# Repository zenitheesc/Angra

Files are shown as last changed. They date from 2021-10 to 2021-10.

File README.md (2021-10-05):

<h1 align="center" style="color:white; background-color:black">Angra</h1>
<h4 align="center">Power bank to power different systems in stratospheric probes</h4>

<p align="center">
	<a href="http://zenith.eesc.usp.br/">
    
    </a>
    <a href="https://eesc.usp.br/">
    
    </a>
    <a href="https://github.com/${{ env.REPOSITORY_FULL_NAME }}/blob/main/LICENSE">
    
    </a>
    <a href="https://github.com/${{ env.REPOSITORY_FULL_NAME }}/issues">
    
    </a>
    <a href="https://github.com/${{ env.REPOSITORY_FULL_NAME }}/commits/main">
    
    </a>
    <a href="https://github.com/${{ env.REPOSITORY_FULL_NAME }}/graphs/contributors">
    
    </a>
    <a href="https://github.com/${{ env.REPOSITORY_FULL_NAME }}/commits/main">
    
    </a>
    <a href="https://github.com/${{ env.REPOSITORY_FULL_NAME }}/issues">
    
    </a>
    <a href="https://github.com/${{ env.REPOSITORY_FULL_NAME }}/pulls">
    
    </a>
</p>

<p align="center">
    <a href="#environment-and-tools">Environment and Tools</a> •
    <a href="#board">Board</a>
</p>

## Environment and tools

This system was designed using Eagle v.9.4.2

## Board

<p align = "center">
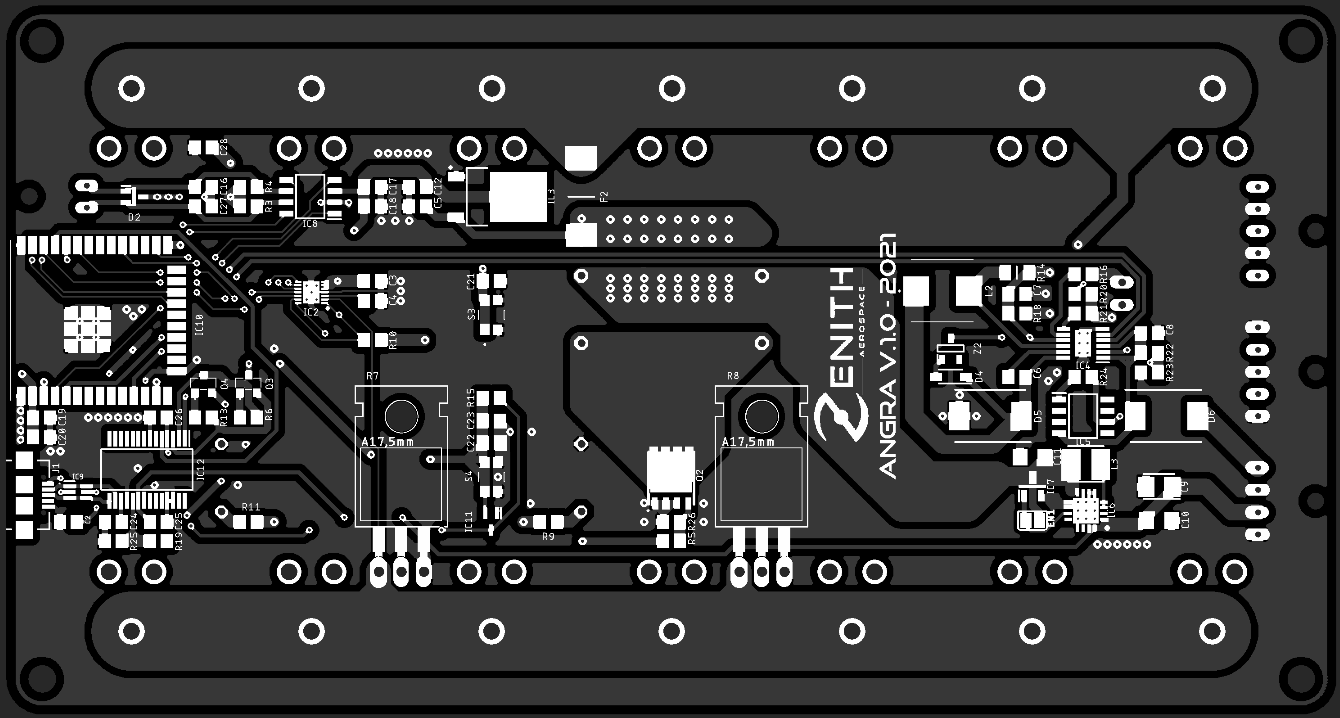
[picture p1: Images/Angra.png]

</p>

It supplies power to up to 5 systems with the voltage of its own batteries and 1 with 5V, in addition to ensuring the health of the batteries, solar charging and wireless monitoring of the status.

---

<p align="center">
    <a href="http://zenith.eesc.usp.br">
    
    </a> 
    <a href="https://www.facebook.com/zenitheesc">
    
    </a> 
    <a href="https://www.instagram.com/zenith_eesc/">
    
    </a>

</p>
<p align = "center">
<a href="zenith.eesc@gmail.com">zenith.eesc@gmail.com</a>
</p>

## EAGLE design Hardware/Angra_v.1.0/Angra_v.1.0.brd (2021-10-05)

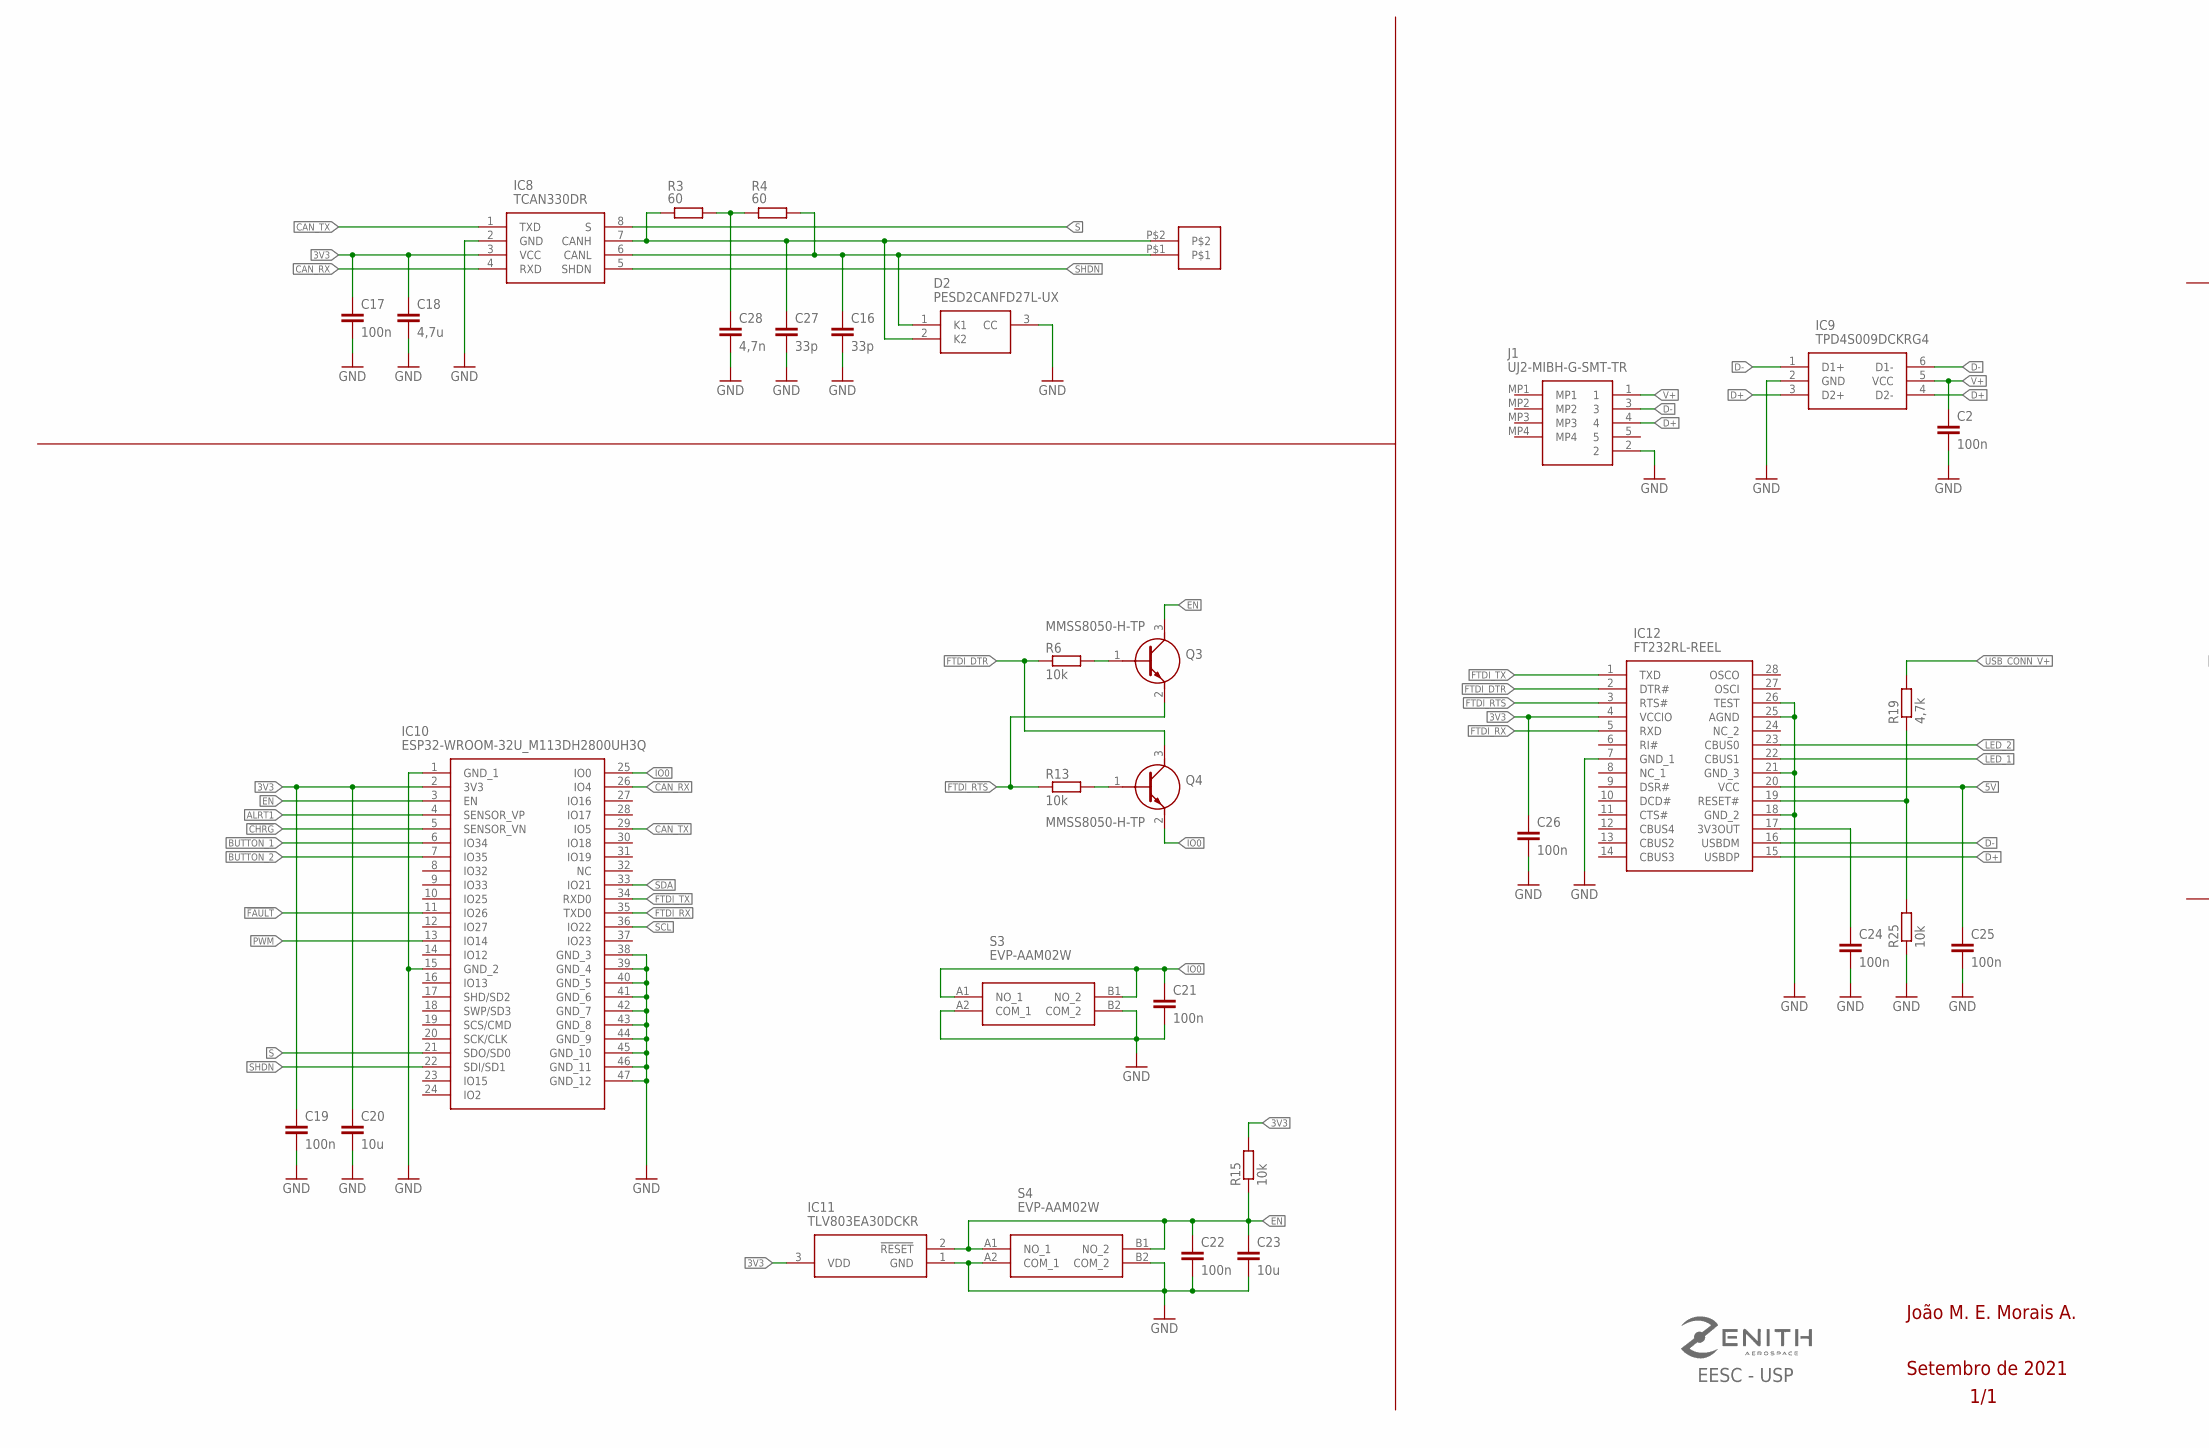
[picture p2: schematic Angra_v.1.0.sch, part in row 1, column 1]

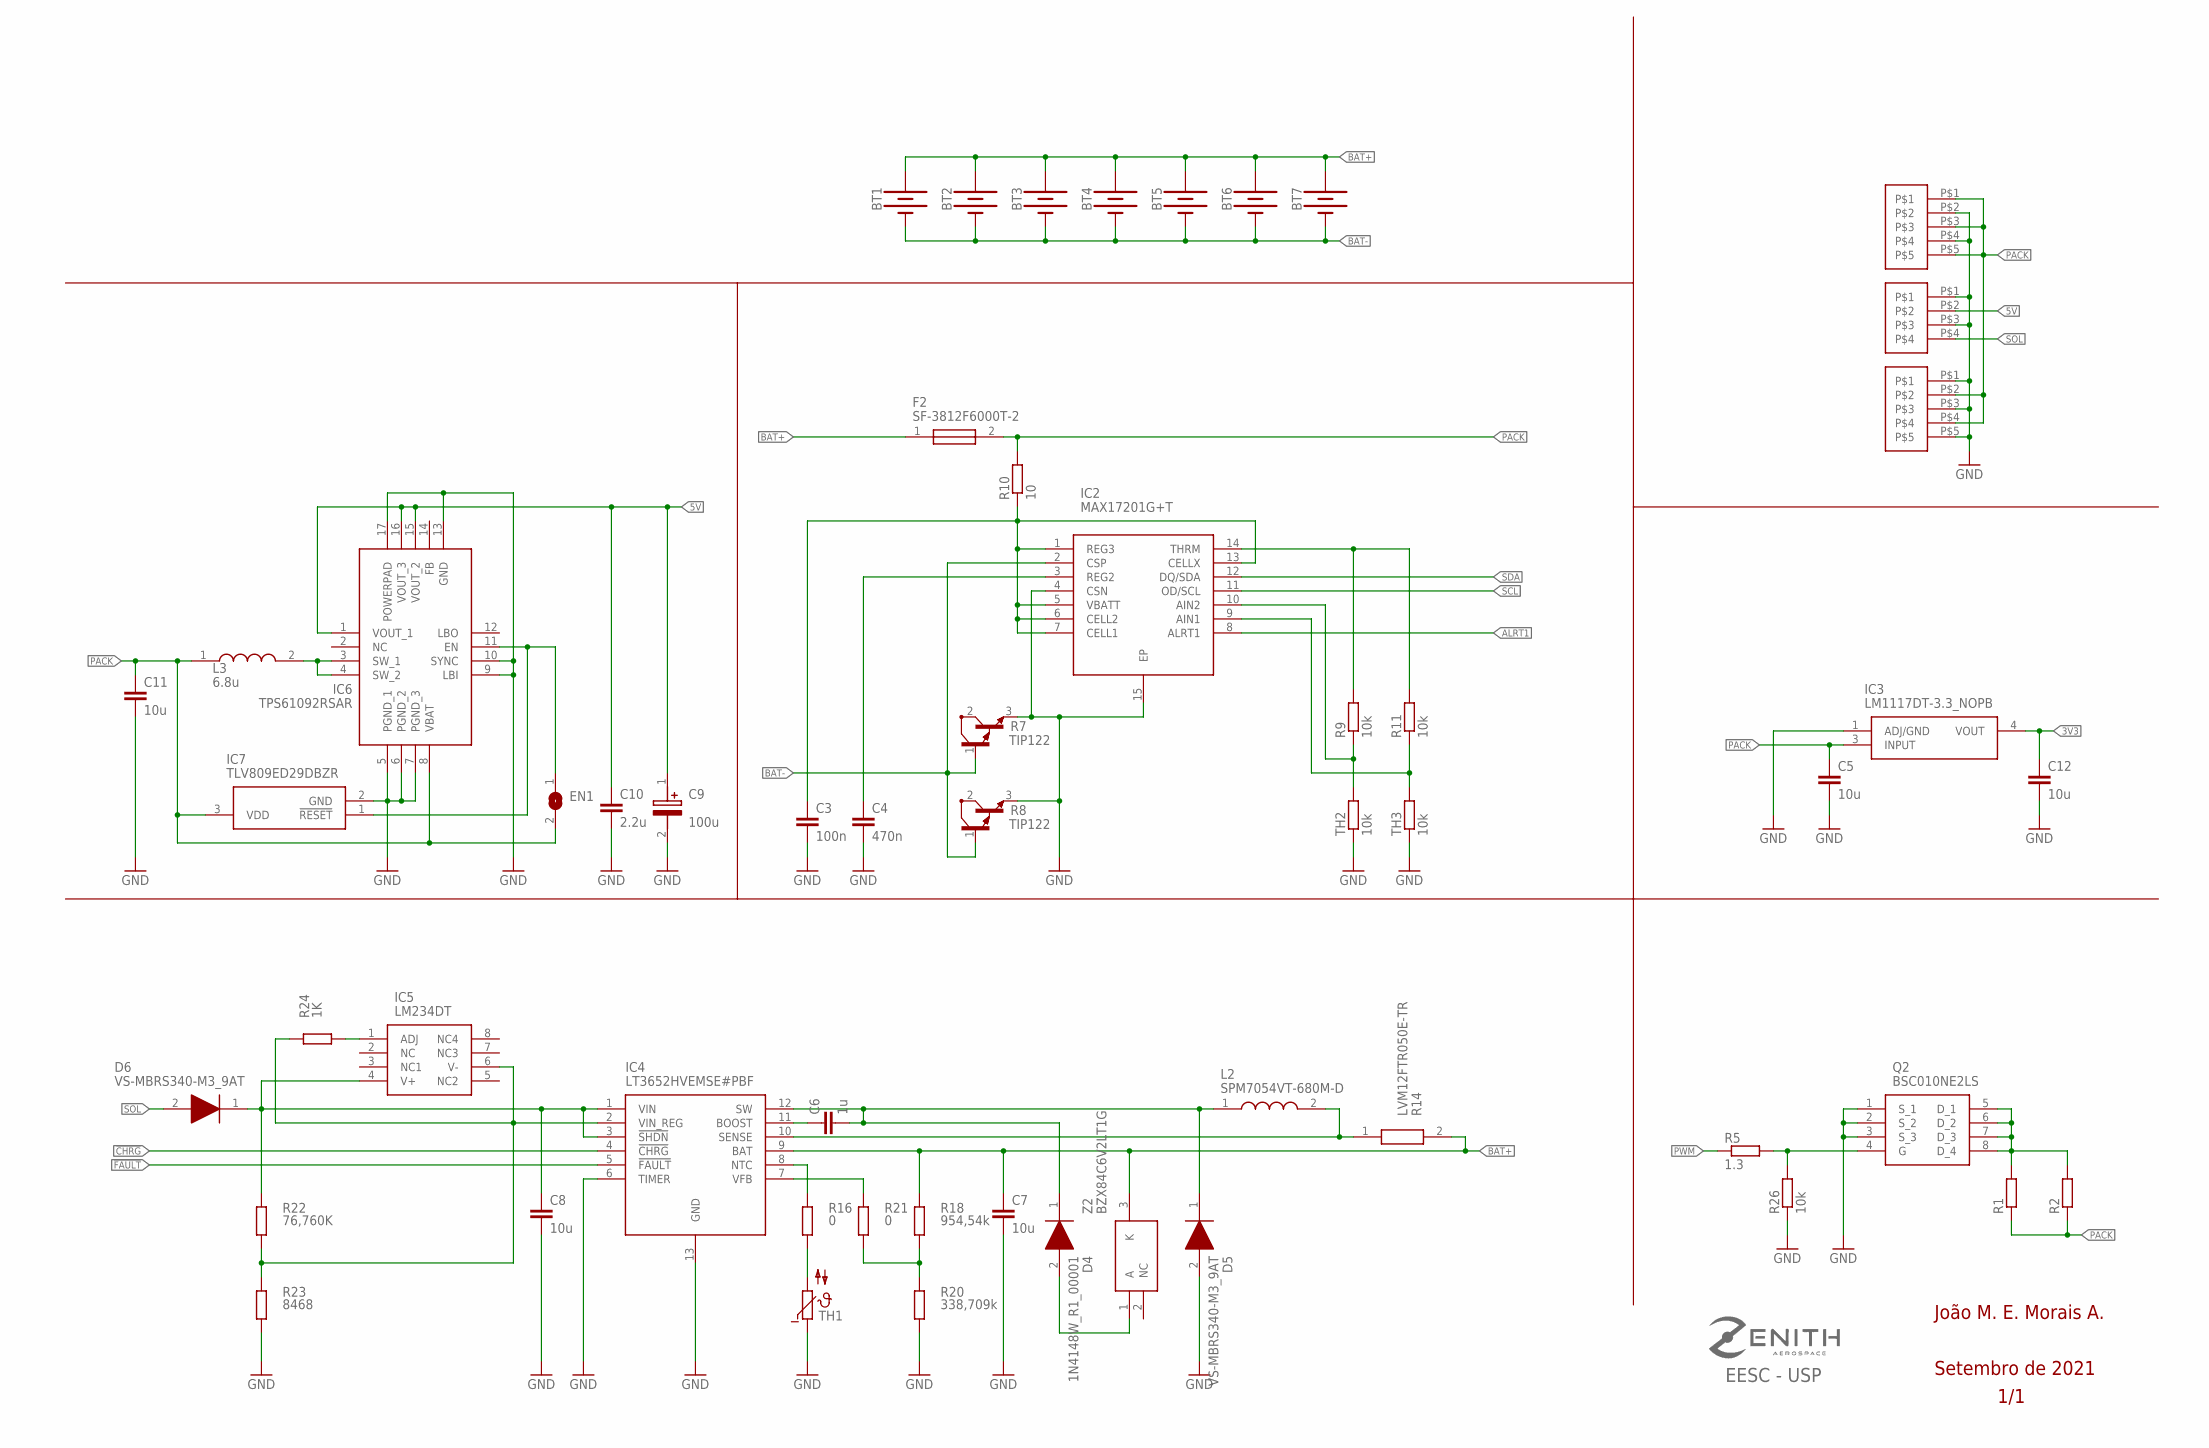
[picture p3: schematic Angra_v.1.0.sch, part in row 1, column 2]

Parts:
BT1, BT2, BT3, BT4, BT5, BT6, BT7: BATTERY-18650; BATTERY_18650-HOLDER
C2, C3, C17, C19, C21, C22, C24, C25, C26: 100n; C0805
C4: 470n; C0805
C5, C7, C8, C12, C20, C23: 10u; C0805
C6: 1u; C0805
C9: 100u; CAPPM3528X210N
C10: 2.2u; C1206
C11: 10u; C1206
C16, C27: 33p; C0805
C18: 4,7u; C0805
C28: 4,7n; C0805
D2: PESD2CANFD27L-UX; SOT65P210X110-3N
D4: 1N4148W_R1_00001; SOD3816X135N
D5, D6: VS-MBRS340-M3_9AT; DIOM7959X262N
EN1: SOLDERJUMPERREFLOW_NOPASTE; SOLDERJUMPER_REFLOW_NOPASTE
F2: SF-3812F6000T-2; FUSC10131X330N
IC2: MAX17201G+T; SON40P300X300X80-15N
IC3: LM1117DT-3.3_NOPB; TO228P991X238-3N
IC4: LT3652HVEMSE#PBF; SOP65P490X110-13N
IC5: LM234DT; SOIC127P600X175-8N@1
IC6: TPS61092RSAR; QFN65P400X400X100-17N
IC7: TLV809ED29DBZR; SOT95P237X112-3N
IC8: TCAN330DR; SOIC127P600X175-8N
IC9: TPD4S009DCKRG4; SOT65P210X110-6N
IC10: ESP32-WROOM-32U_M113DH2800UH3Q; ESP32WROOM32UM113DH2800UH3Q0
IC11: TLV803EA30DCKR; SOT65P210X110-3N@1
IC12: FT232RL-REEL; SOP65P778X200-28N
J1: UJ2-MIBH-G-SMT-TR; UJ2MIBHGSMTTR
L2: SPM7054VT-680M-D; SPM7054VT
L3: 6.8u; INDPM4040X210N
Q2: BSC010NE2LS; PG-TDSON-8
Q3, Q4: MMSS8050-H-TP; SI2305TP
R1, R2: R-EU_0207/7; 0207/7
R3, R4: 60; R0805
R5: 1.3; R0805
R6, R9, R11, R13, R15, R25, R26: 10k; R0805
R7, R8: TIP122; TO220
R10: 10; R0805
R14: LVM12FTR050E-TR; RESC3016X70N
R16, R21: 0; R0805
R18: 954,54k; R0805
R19: 4,7k; R0805
R20: 338,709k; R0805
R22: 76,760K; R0805
R23: 8468; R0805
R24: 1K; R0805
S3, S4: EVP-AAM02W; EVPAAM02W
TH1: NTC640; P640
TH2, TH3: 10k; 0207/7
U$1: S02B-XASS-1
U$2, U$3: S05B-XASS-1
U$4: S04B-XASS-1
Z2: BZX84C6V2LT1G; SOT96P237X111-3N

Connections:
3V3: C12.1, C17.1, C18.1, C19.1, C20.1, C26.1, IC3.4 (VOUT), IC8.3 (VCC), IC10.2 (3V3), IC11.3 (VDD), IC12.4 (VCCIO), R15.2
5V: C9.1 (+), C10.1, C25.1, IC6.1 (VOUT_1), IC6.15 (VOUT_2), IC6.16 (VOUT_3), IC12.20 (VCC), U$4.P$2
!CHRG: IC4.4 (!CHRG), IC10.5 (SENSOR_VN)
!FAULT: IC4.5 (!FAULT), IC10.11 (IO26)
ALRT1: IC2.8 (ALRT1), IC10.4 (SENSOR_VP)
BAT+: BT1.PWR@1 (+), BT2.PWR@1 (+), BT3.PWR@1 (+), BT4.PWR@1 (+), BT5.PWR@1 (+), BT6.PWR@1 (+), BT7.PWR@1 (+), C7.1, F2.1, IC4.9 (BAT), R14.2, R18.1, Z2.3 (K)
BAT-: BT1.GND@1 (-), BT2.GND@1 (-), BT3.GND@1 (-), BT4.GND@1 (-), BT5.GND@1 (-), BT6.GND@1 (-), BT7.GND@1 (-), IC2.2 (CSP), R7.1 (B), R8.1 (B)
BUTTON_1: IC10.6 (IO34)
BUTTON_2: IC10.7 (IO35)
CANH: C27.1, D2.2 (K2), IC8.7 (CANH), R3.2, U$1.P$2
CANL: C16.1, D2.1 (K1), IC8.6 (CANL), R4.1, U$1.P$1
CAN_RX: IC8.4 (RXD), IC10.26 (IO4)
CAN_TX: IC8.1 (TXD), IC10.29 (IO5)
D+: IC9.3 (D2+), IC9.4 (D2-), IC12.15 (USBDP), J1.4
D-: IC9.1 (D1+), IC9.6 (D1-), IC12.16 (USBDM), J1.3
EN: C22.1, C23.1, IC10.3 (EN), IC11.2 (!RESET), Q3.3 (C), R15.1, S4.A1 (NO_1), S4.B1 (NO_2)
FTDI_DTR: IC12.2 (DTR#), Q4.3 (C), R6.1
FTDI_RTS: IC12.3 (RTS#), Q3.2 (E), R13.1
FTDI_RX: IC10.35 (TXD0), IC12.5 (RXD)
FTDI_TX: IC10.34 (RXD0), IC12.1 (TXD)
GND: C2.2, C3.2, C4.2, C5.2, C7.2, C8.2, C9.2 (-), C10.2, C11.2, C12.2, C16.2, C17.2, C18.2, C19.2, C20.2, C21.2, C22.2, C23.2, C24.2, C25.2, C26.2, C27.2, C28.2, D2.3 (CC), D5.2 (A), IC2.4 (CSN), IC2.15 (EP), IC3.1 (ADJ/GND), IC4.6 (TIMER), IC4.13 (GND), IC6.5 (PGND_1), IC6.6 (PGND_2), IC6.7 (PGND_3), IC6.9 (LBI), IC6.10 (SYNC), IC6.13 (GND), IC6.17 (POWERPAD), IC7.2 (GND), IC8.2 (GND), IC9.2 (GND), IC10.1 (GND_1), IC10.15 (GND_2), IC10.38 (GND_3), IC10.39 (GND_4), IC10.40 (GND_5), IC10.41 (GND_6), IC10.42 (GND_7), IC10.43 (GND_8), IC10.44 (GND_9), IC10.45 (GND_10), IC10.46 (GND_11), IC10.47 (GND_12), IC11.1 (GND), IC12.7 (GND_1), IC12.18 (GND_2), IC12.21 (GND_3), IC12.25 (AGND), IC12.26 (TEST), J1.2, Q2.1 (S_1), Q2.2 (S_2), Q2.3 (S_3), R7.3 (E), R8.3 (E), R20.2, R23.2, R25.1, R26.1, S3.A2 (COM_1), S3.B2 (COM_2), S4.A2 (COM_1), S4.B2 (COM_2), TH1.1, TH2.1, TH3.1, U$2.P$2, U$2.P$4, U$3.P$1, U$3.P$3, U$3.P$5, U$4.P$1, U$4.P$3
IO0: C21.1, IC10.25 (IO0), Q4.2 (E), S3.A1 (NO_1), S3.B1 (NO_2)
LED_1: IC12.22 (CBUS1)
LED_2: IC12.23 (CBUS0)
unnamed: C28.1, R3.1, R4.2
unnamed: IC6.3 (SW_1), IC6.4 (SW_2), L3.2
unnamed: EN1.1, IC6.11 (EN), IC7.1 (!RESET)
unnamed: Q2.4 (G), R5.2, R26.2
unnamed: Q4.1 (B), R13.2
unnamed: Q3.1 (B), R6.2
unnamed: C3.1, IC2.1 (REG3), IC2.5 (VBATT), IC2.6 (CELL2), IC2.7 (CELL1), IC2.13 (CELLX), R10.1
unnamed: C4.1, IC2.3 (REG2)
unnamed: IC2.14 (THRM), R9.2, R11.2
unnamed: IC2.10 (AIN2), R9.1, TH2.2
unnamed: IC2.9 (AIN1), R11.1, TH3.2
unnamed: IC12.19 (RESET#), R19.1, R25.2
unnamed: C24.1, IC12.17 (3V3OUT)
unnamed: IC4.10 (SENSE), L2.2, R14.1
unnamed: IC4.8 (NTC), R16.1
unnamed: R16.2, TH1.2
unnamed: C6.2, D4.1 (K), D5.1 (K), IC4.12 (SW), L2.1
unnamed: IC4.7 (VFB), R21.1
unnamed: R18.2, R20.1, R21.2
unnamed: C6.1, IC4.11 (BOOST)
unnamed: C8.1, D6.1 (K), IC4.1 (VIN), IC4.3 (!SHDN), IC5.4 (V+), R22.1
unnamed: IC4.2 (VIN_REG), IC5.6 (V-), R22.2, R23.1, R24.1
unnamed: IC5.1 (ADJ), R24.2
unnamed: D4.2 (A), Z2.1 (A)
PACK: C5.1, C11.1, EN1.2, F2.2, IC3.3 (INPUT), IC6.8 (VBAT), IC7.3 (VDD), L3.1, R1.1, R2.1, R10.2, U$2.P$1, U$2.P$3, U$2.P$5, U$3.P$2, U$3.P$4
PWM: IC10.13 (IO14), R5.1
RL: Q2.5 (D_1), Q2.6 (D_2), Q2.7 (D_3), Q2.8 (D_4), R1.2, R2.2
S: IC8.8 (S), IC10.21 (SDO/SD0)
SCL: IC2.11 (OD/SCL), IC10.36 (IO22)
SDA: IC2.12 (DQ/SDA), IC10.33 (IO21)
SHDN: IC8.5 (SHDN), IC10.22 (SDI/SD1)
SOL: D6.2 (A), U$4.P$4
USB_CONN_V+: R19.2
V+: C2.1, IC9.5 (VCC), J1.1

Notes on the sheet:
C:/Users/marcu/Desktop/Ensino Superior/Graduação - Eng Elétrica/Zenith/zenith-v2.bmp
EESC - USP
Setembro de 2021
1/1
João M. E. Morais A.

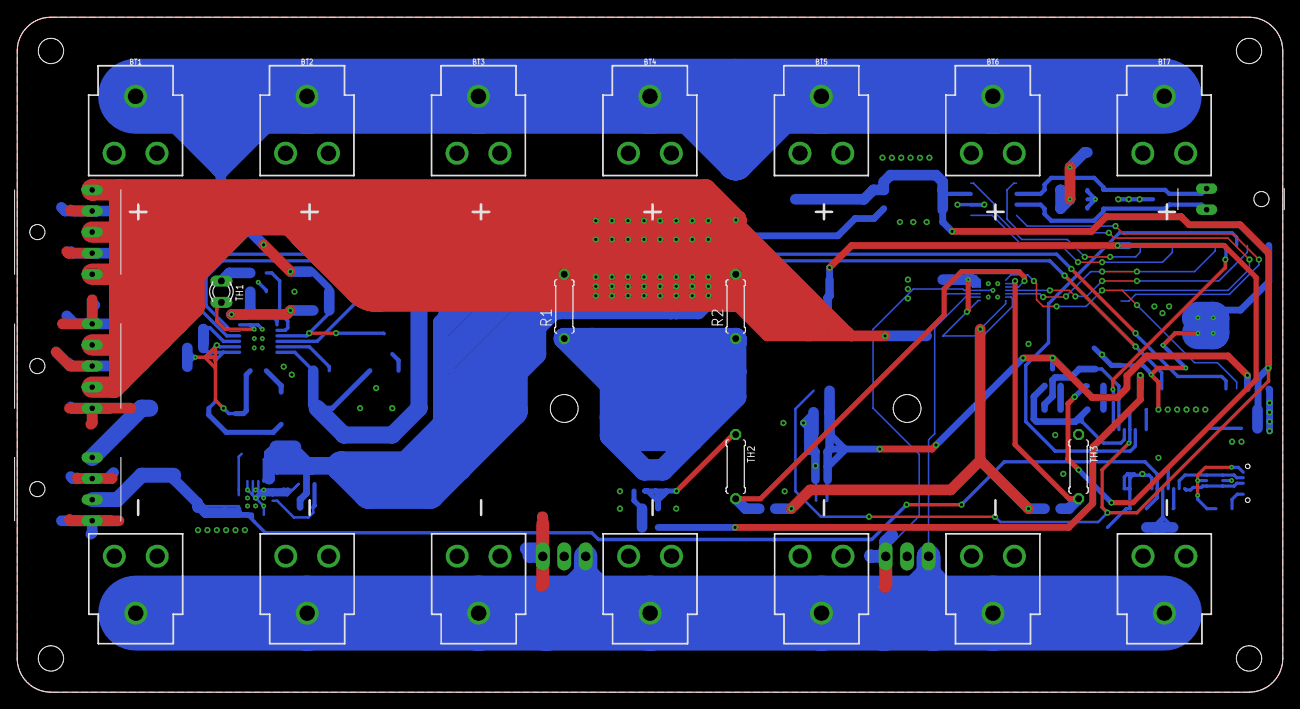
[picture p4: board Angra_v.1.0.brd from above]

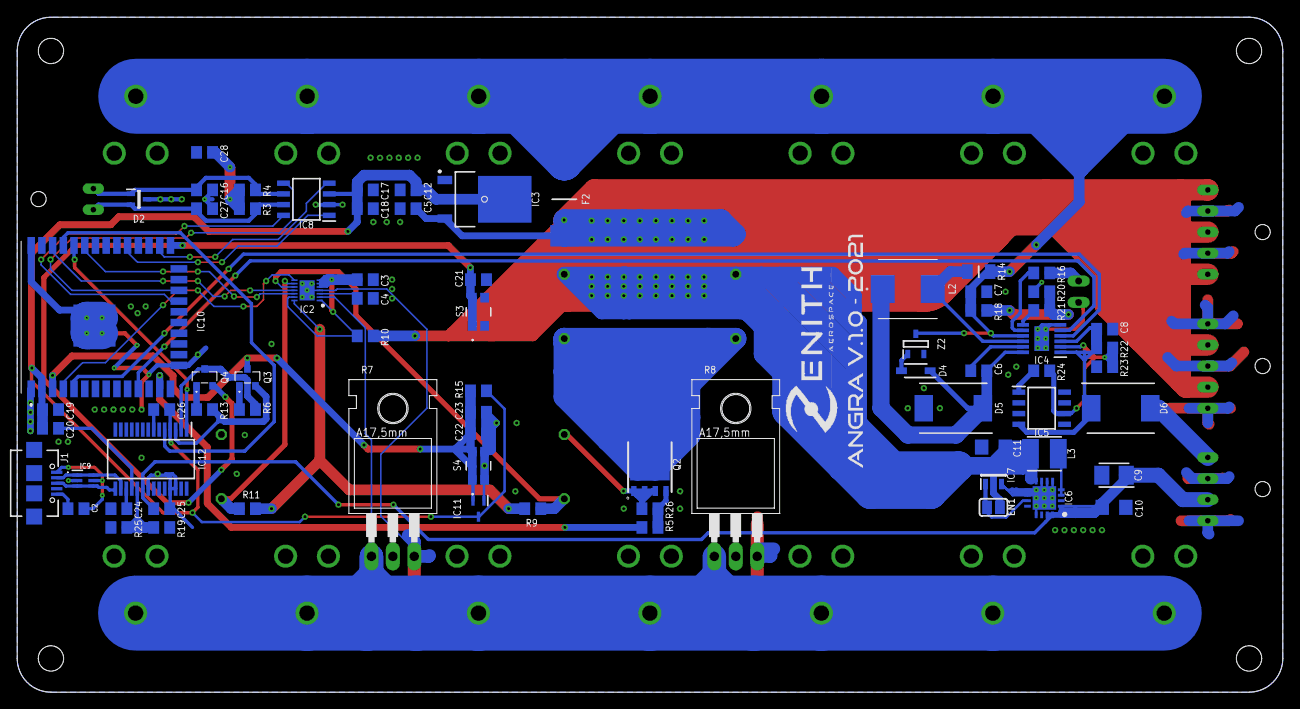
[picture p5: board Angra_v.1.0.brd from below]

Board: 2 copper layers, 150.0 x 80.0 mm, 88 parts (72 on the bottom side), 53 nets.

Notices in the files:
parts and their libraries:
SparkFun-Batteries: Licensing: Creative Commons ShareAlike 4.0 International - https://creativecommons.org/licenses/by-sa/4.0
